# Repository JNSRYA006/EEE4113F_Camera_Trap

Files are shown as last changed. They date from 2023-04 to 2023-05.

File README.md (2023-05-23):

# EEE4113F Design Project
This repo serves the purpose of collating all of the work done by group members in the design process of the smart camera trap interfacing module.

# Repository Structure
## Sub-modules
1. Power Module
2. Base Station
3. Sensing and Camera Trap Interfacing
4. Remote Access & UI

# Aditional Info
## Group Members
JNSRYA006, KGKOMO001, ADNSIG001, MKHAND025

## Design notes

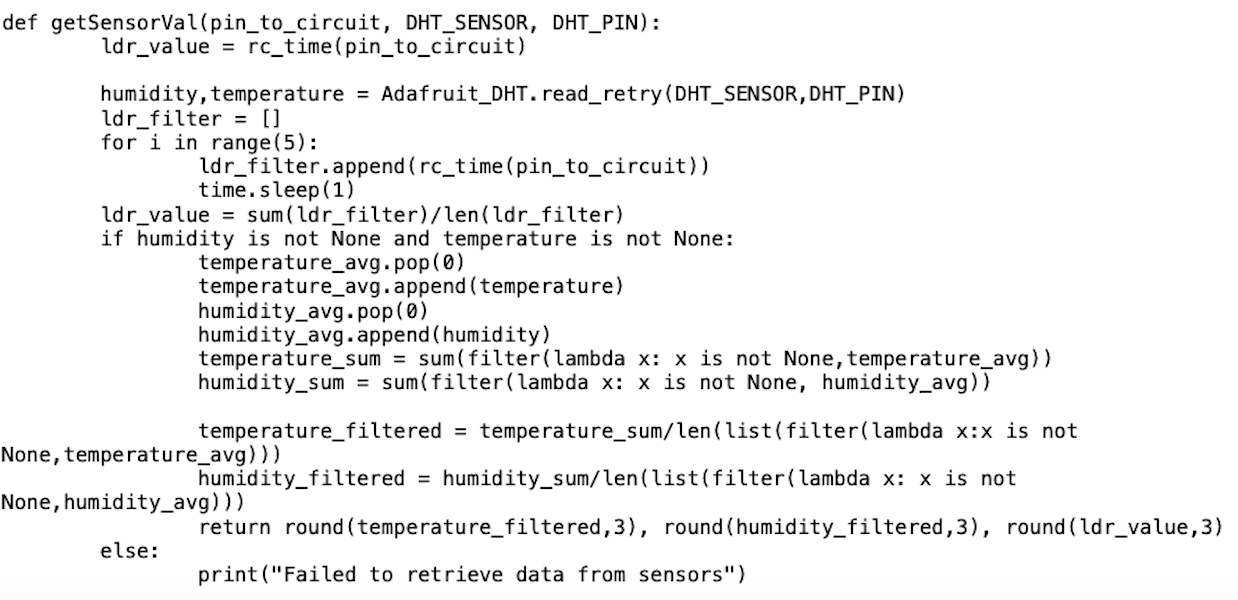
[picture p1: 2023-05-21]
Climate Sensing/end.png

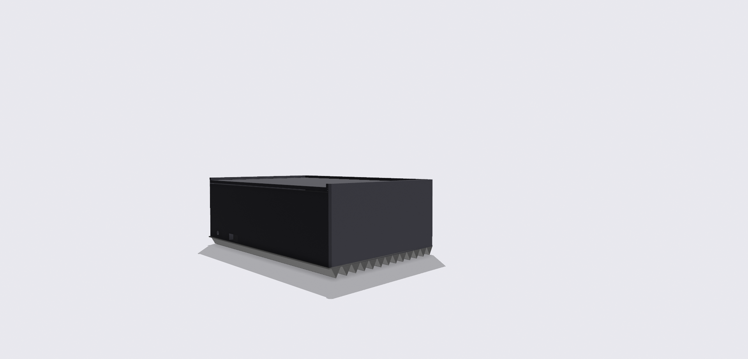
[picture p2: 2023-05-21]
Base Station/Housing/Housing_image_3.png

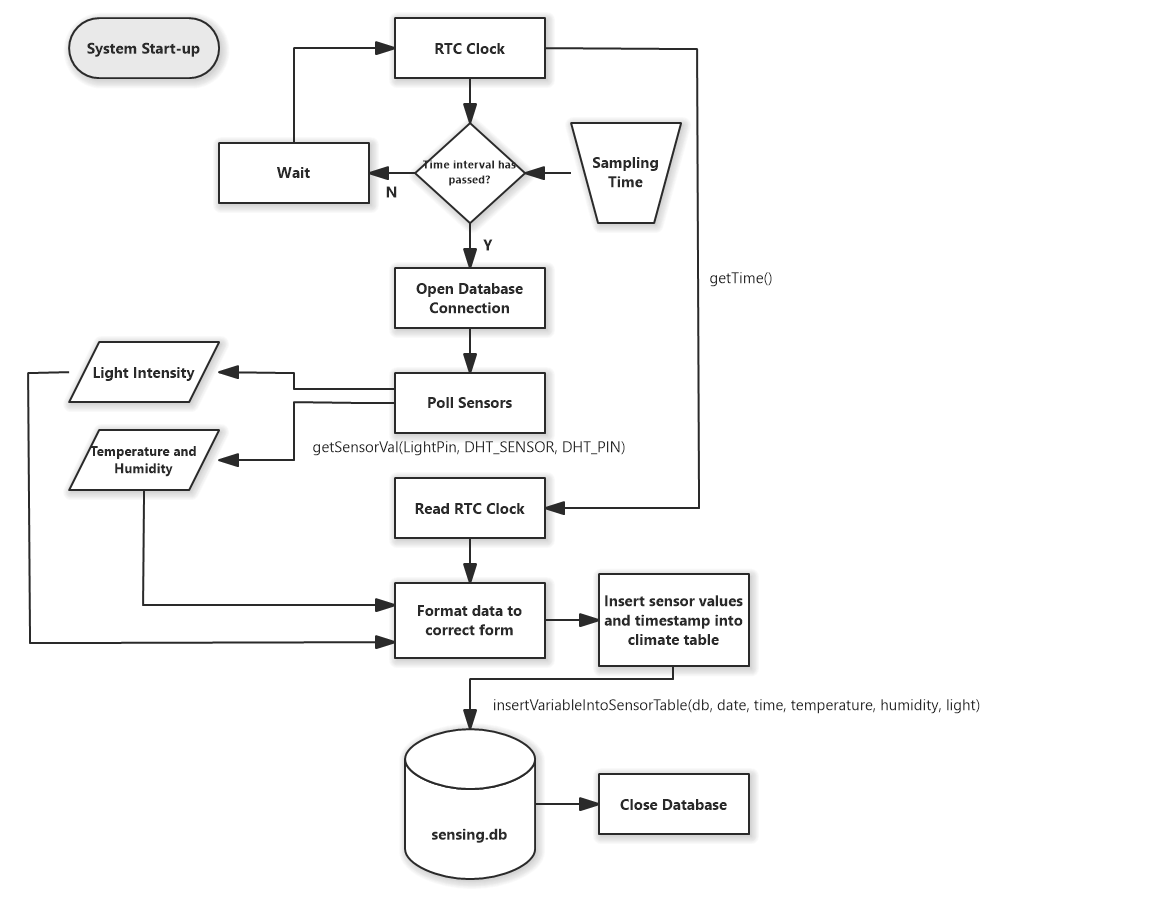
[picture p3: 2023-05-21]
Base Station/db code/Sensing_db_schema.png

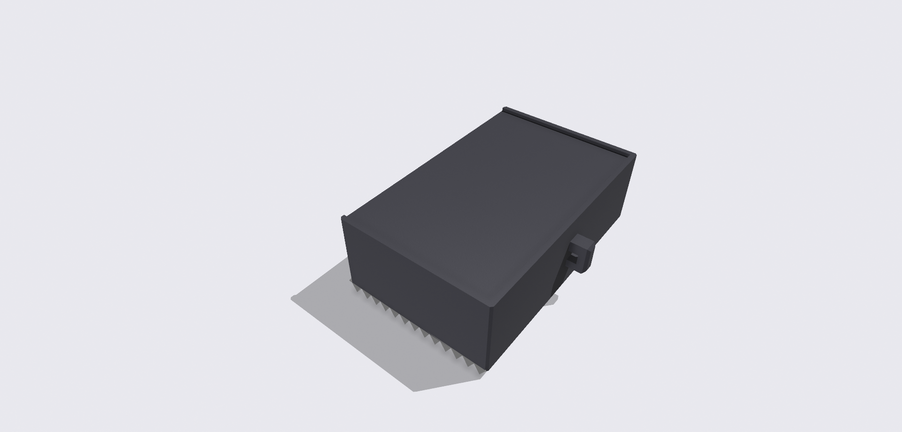
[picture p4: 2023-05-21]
Base Station/Housing/Housing_image_5.png

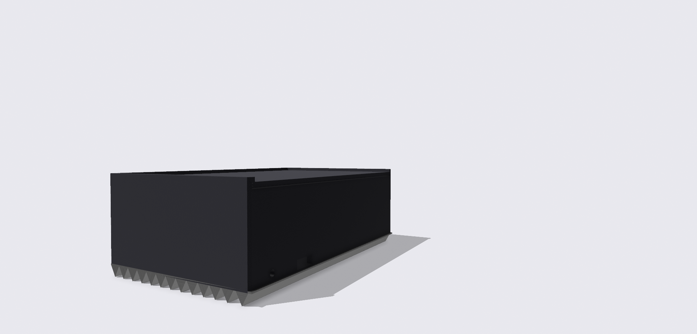
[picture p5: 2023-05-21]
Base Station/Housing/Housing_image_6.png

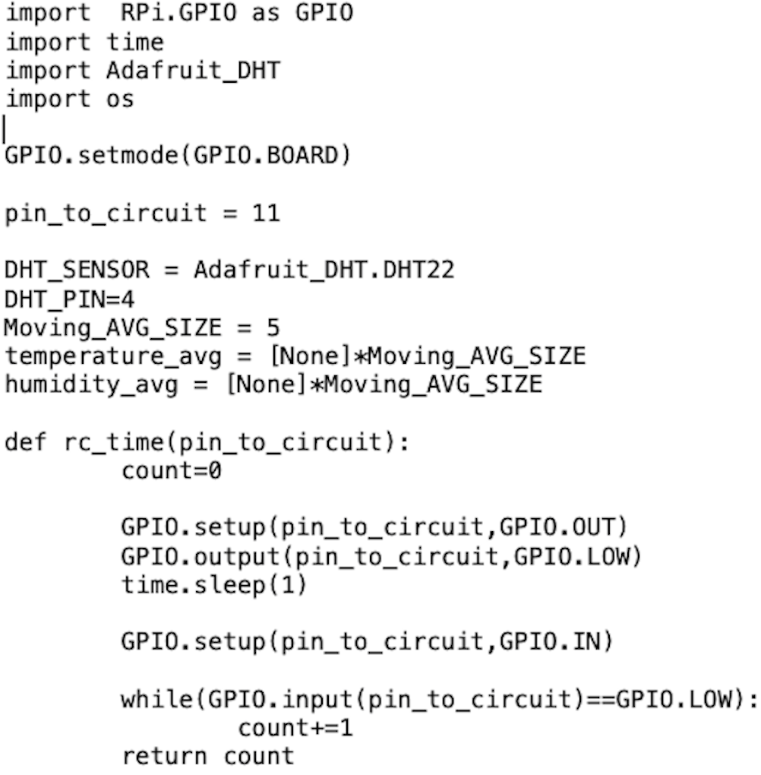
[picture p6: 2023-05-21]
Climate Sensing/begin.png

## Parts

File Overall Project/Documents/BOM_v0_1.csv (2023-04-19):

Item | Description | Quantity | Link | Price
Power Submodule
18650 Battery | Samsung 18650 3500mAh 3.7V Lion Battery | 2 | https://www.robotics.org.za/INR18650-35E | R135.70
LM1117 | 3.3V Voltage Regulator | 1 | White Lab
LM7805 | 5V Voltage Regulator | 1 | White Lab
Battery Protection Board | 2S 7.4V 8A 18650 Lithium Battery Protection Board | 1 | https://www.robofactory.co.za/charging-modules/642-2s-74v-8a-18650-lithium-battery-protection-board.html | R40.00
INA219 | Current Sensing Module | 1 | https://www.communica.co.za/products/hkd-ina219-dc-current-sensor?variant=44293660311852 | R65.00
DHT11 | Temperature & Humidity Sensor | 1 | https://www.communica.co.za/products/hkd-temp-humd-dht11-sensor-orig?variant=44293638062380 | R39.00
DS18B20 | Temperature Sensor | 1 | https://www.communica.co.za/products/ds18b20 | R73.51
LM2937-ET | LDO 3.3V Regulator |  | White Lab
Interfacing Module & Sensing
SD Card Extender | Male SD card with flat cable out - will connect to Pi via GPIO pins | 1 | https://www.pishop.co.za/store/sd-to-sd-extension-cable-45cm | R60.38
IDC Connector | From flat ribbon (SD Extender) to GPIO pins of Pi. Needs to be to female to slot onto Pi - Ideally include strain relief | 1 | https://www.communica.co.za/products/722200?variant=39321986596937 | R3.11 | Need to confirm the number of pins (When SD extender arrives) - Think 10
Temperature & Humidity Sensor | CMU TEMP+HUMD DHT22 SENSOR | 1 | https://www.communica.co.za/products/cmu-temp-humd-dht22-sensor?variant=39983963570249 | R79.01
Light Intensity Sensor | BMT MAX44009 I2C AMB LIGHT SENSOR | 1 | https://www.communica.co.za/products/bmt-max44009-i2c-amb-light-senso?variant=40197174624329 | R190.00
Micro USB cable | For powering the Pi Zero | 1 | https://www.communica.co.za/products/hkd-usb-cable-1m-am-micro?variant=39943510917193 | R18.00
Base Station Module
Raspberry Pi Zero | Will do all the data processing of the device and has WiFi to create the local network that will be used for remote access | 1 | White Lab
16GB Micro SD Card | For use in the Pi and will act as the SD card that the camera trap uses | 1 | https://www.communica.co.za/products/micro-sd-card-16gb-adpt-netac?variant=31953028120649 | R75.00
Remote Access Module
None - all software based
 |  |  | Total | R778.71

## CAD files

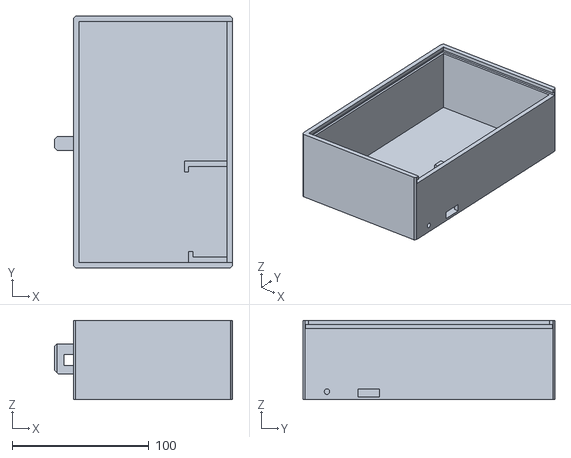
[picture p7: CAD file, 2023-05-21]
Base Station/Housing/Housing_v2.stl
130.0 x 184.0 x 58.0

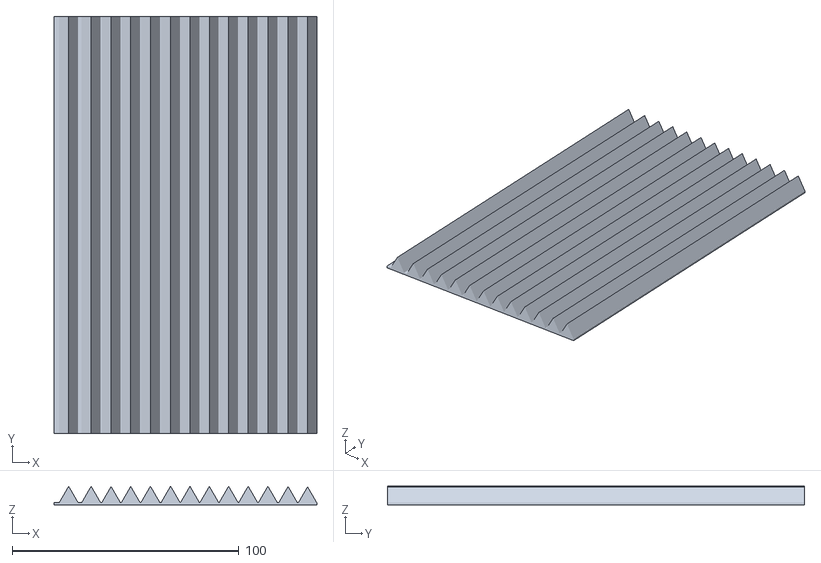
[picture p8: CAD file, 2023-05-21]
Base Station/Housing/Heat_sink_v2.stl
116.0 x 184.0 x 8.29

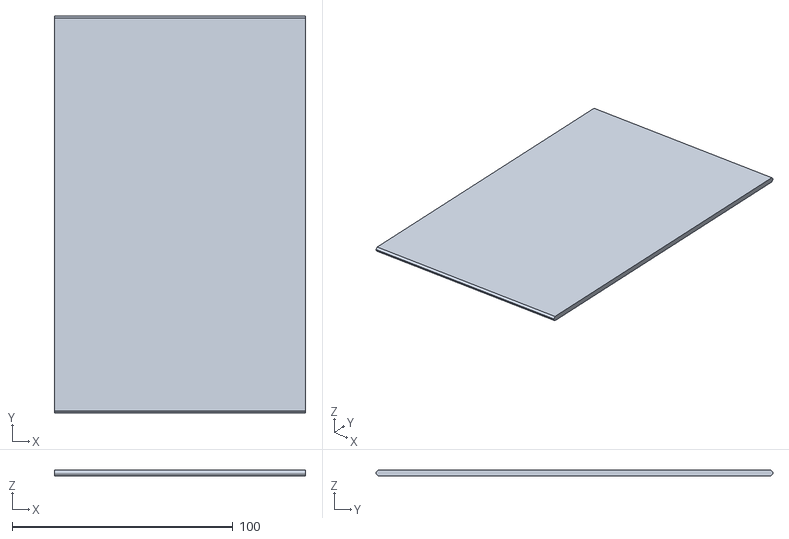
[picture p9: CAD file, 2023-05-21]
Base Station/Housing/Lid_v2.stl
114.0 x 180.0 x 2.50

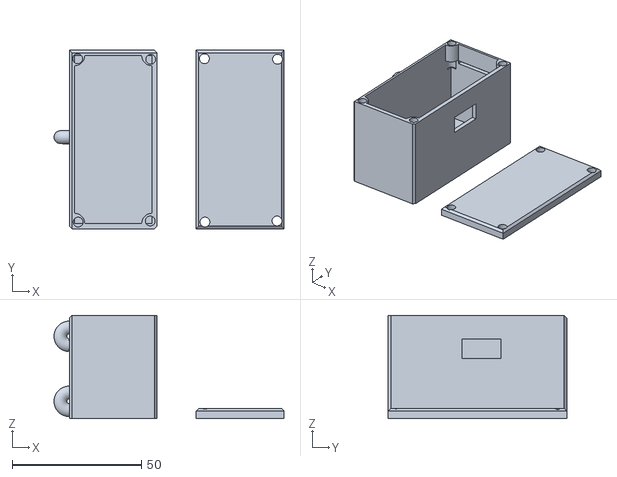
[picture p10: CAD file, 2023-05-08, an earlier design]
Base Station/Housing/Housing_v1.stl
88.9 x 69.0 x 40.0

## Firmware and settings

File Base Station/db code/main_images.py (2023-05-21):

# Main image storage script

import sys
import time
from datetime import datetime
import time


sys.path.insert(0,'/home/pi/')
import terminal_RTC
import image_monitor_db
import images

def main():
    timeStr = terminal_RTC.getTime() # Get current time every second
    print(timeStr)
    print("Waiting until next interval")
    files_names, files_paths = images.getListImageandPath("/home/pi/images/")
    # String values in timeStr
    # 18 = 0x seconds
    # 17 = x0 seconds
    # 15 = 0x mins
    # 14 = x0 mins
    # 12 = 0x hours
    # 11 = x0 hours
    if timeStr[17] == '0' and timeStr[18] == '0':
        for i in range(0,len(files_paths)):
            image_monitor_db.insertVaribleIntoImageTable('images.db', timeStr[:10], timeStr[11:-14], files_names[i], files_paths[i])
    
    time.sleep(0.5)



while True:
    main()

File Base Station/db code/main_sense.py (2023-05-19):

# Test main file to get sensor data
import sys
import time
from datetime import datetime
import  RPi.GPIO as GPIO
import time
import Adafruit_DHT


sys.path.insert(0,'/home/pi/')
import terminal_RTC
import return_sense
import sensor_monitor_db


pin_to_circuit = 11

DHT_SENSOR = Adafruit_DHT.DHT22
DHT_PIN=4
Moving_AVG_SIZE = 5
temperature_avg = [None]*Moving_AVG_SIZE
humidity_avg = [None]*Moving_AVG_SIZE

def main():
    timeStr = terminal_RTC.getTime() # Get current time every second
    print(timeStr)
    print("Waiting until next interval")
    # String values in timeStr
    # 18 = 0x seconds
    # 17 = x0 seconds
    # 15 = 0x mins
    # 14 = x0 mins
    # 12 = 0x hours
    # 11 = x0 hours
    if timeStr[18] == '0':
        temperature, humidity, light = return_sense.getSensorVal(pin_to_circuit,DHT_SENSOR,DHT_PIN)
        sensor_monitor_db.insertVaribleIntoSensorTable('sensing.db', timeStr[:10], timeStr[11:-14], temperature, humidity, light)
    
    
    time.sleep(0.5)

while True:
    main()

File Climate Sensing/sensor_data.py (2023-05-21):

import  RPi.GPIO as GPIO
import time
import Adafruit_DHT
import os 

GPIO.setmode(GPIO.BOARD)

pin_to_circuit = 11

DHT_SENSOR = Adafruit_DHT.DHT22
DHT_PIN=4
Moving_AVG_SIZE = 5
temperature_avg = [None]*Moving_AVG_SIZE
humidity_avg = [None]*Moving_AVG_SIZE

def get_light_category(light_value):
	if light_value <100:
		return 'Very bright'
	elif light_value <500:
		return 'bright'
	elif light_value <1000:
		return 'dark/shady'
	else:
		return 'very dark'

try:
	f = open('/home/pi/sensor_data.csv','a+')
	if os.start('/home/pi/sensor_data.csv').st_size==0:
		f.write('{0} {1} {2:0.1f}*C {3:0.1f}% {4}\r\n'.format(time.strftime('%m/%d/%y'),time.strftime('%H:%M'),temperature_filtered,humidity_filtered,ldr_value,Light_category))

except:
	pass

def rc_time(pin_to_circuit):
	count=0

	GPIO.setup(pin_to_circuit,GPIO.OUT)
	GPIO.output(pin_to_circuit,GPIO.LOW)
	time.sleep(1)

	GPIO.setup(pin_to_circuit,GPIO.IN)

	while(GPIO.input(pin_to_circuit)==GPIO.LOW):
		count+=1
	return count 
while True :
	ldr_value = rc_time(pin_to_circuit)

	humidity,temperature = Adafruit_DHT.read_retry(DHT_SENSOR,DHT_PIN)
	ldr_filter = []
	for i in range(5):
		ldr_filter.append(rc_time(pin_to_circuit))
		time.sleep(1)
	ldr_value = sum(ldr_filter)/len(ldr_filter)
	if humidity is not None and temperature is not None:
		temperature_avg.pop(0)
		temperature_avg.append(temperature)
		humidity_avg.pop(0)
		humidity_avg.append(humidity)
		temperature_sum = sum(filter(lambda x: x is not None,temperature_avg))
		humidity_sum = sum(filter(lambda x: x is not None, humidity_avg))

		temperature_filtered = temperature_sum/len(list(filter(lambda x:x is not None,temperature_avg)))
		humidity_filtered = humidity_sum/len(list(filter(lambda x: x is not None,humidity_avg)))
		light_category = get_light_category(ldr_value)
		f.write('{0},{1},{2:0.1f}*C,{3:0.1f}%,{4},{5}\r\n'.format(time.strftime('%m/%d/%y'),time.strftime('%H:%M'),temperature_filtered, humidity_filtered,ldr_value,light_category))
		print('Temperature={0:0.1f}*C Humidity={1:0.1f}% Light Intensity={2} ({3})'.format(temperature_filtered,humidity_filtered,ldr_value,light_category))
	else:
		print("Falied to retrieve data from sensors")

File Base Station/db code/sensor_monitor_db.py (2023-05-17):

# Import appropriate packages
import sqlite3
import sys
from datetime import datetime

sys.path.insert(0,'/home/group10/')
sys.path.insert(0,'/home/group10/sensor_data')

# Returns an object to connect to given database text string
def connectDB(dbName):
    #print "Opened database successfully"
    return sqlite3.connect(dbName)

# Inserts an entry with the following format:
# db: database name (string)
# date: From RTC clock (string)
# time: From RTC clock (string)
# temperature: From DHT22 (real)
# humidity: From DHT22 (real)
def insertVaribleIntoSensorTable(db, date, time, temperature, humidity, light):
    try:
        conn = sqlite3.connect(db)
        cursor = conn.cursor()
        print("Connected to SQLite Database")

        cursor.execute("INSERT INTO climate (date, time, temperature, humidity, light) VALUES (?, ?, ?, ?, ?)", (date, time, temperature, humidity, light))
        conn.commit()
        print("Sensor values successfully stored in database")

        cursor.close()

    except sqlite3.Error as error:
        print("Failed to insert sensor values into climate table", error)
    finally:
        if conn:
            conn.close()
            print("The SQLite connection is closed")

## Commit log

2023-04-19 Upload BOM v0_1
    [BOM_v0_1.csv]
2023-04-19 Udate BOM v0_1
    [BOM_v0_1.csv]
2023-05-08 Added v1 of housing
    [Housing_v1.stl]
2023-05-16 Store sensor values in DB
2023-05-18 begining of powerpoint
2023-05-19 Last updates to powerpoint and code
2023-05-21 Add files via upload
    Sensor Code
2023-05-21 Upload all base station code
    [Heat_sink_v2.stl, Housing_v2.stl, Lid_v2.stl]
2023-05-21 Update to db flowcharts
